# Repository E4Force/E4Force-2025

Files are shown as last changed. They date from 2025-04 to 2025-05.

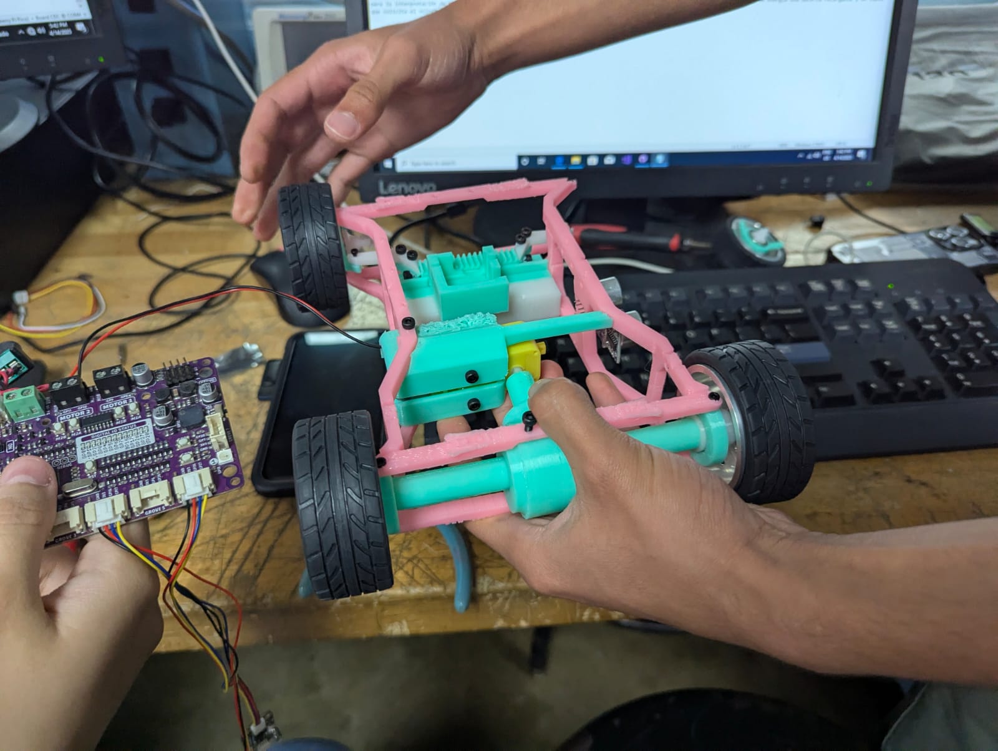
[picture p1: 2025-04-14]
other/prototype_original_mechanics.jpg

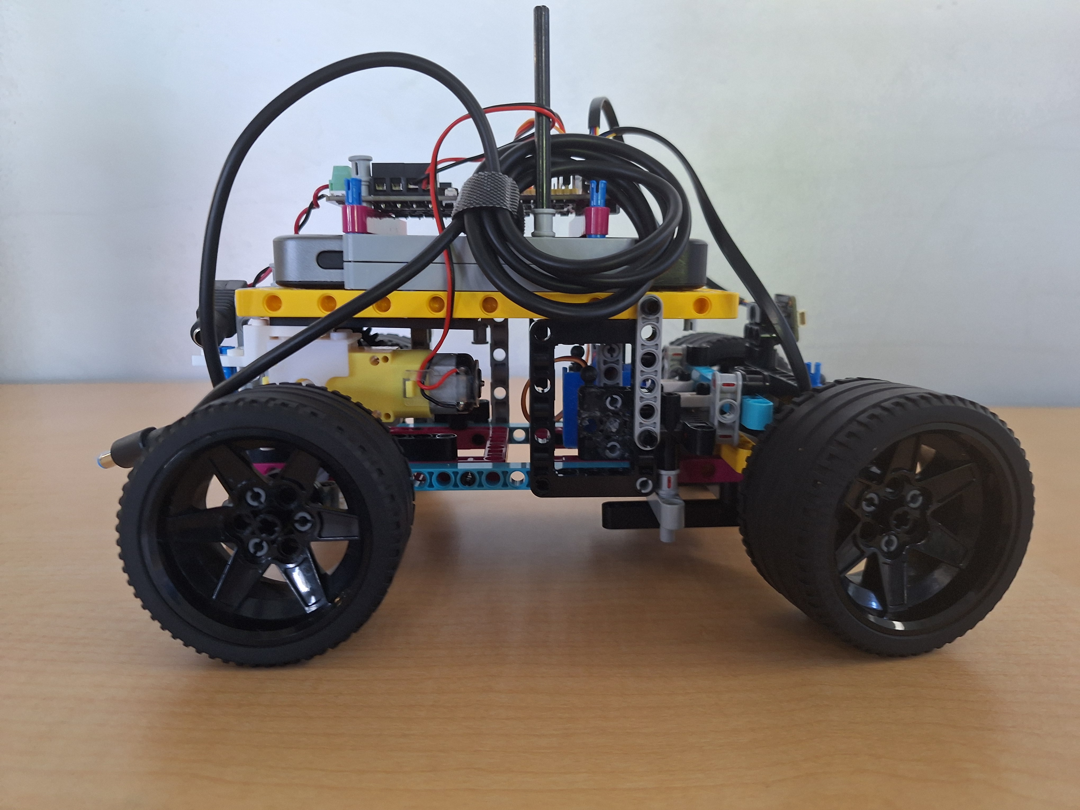
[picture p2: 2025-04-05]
v-photos/V1_car/20250405_082826.jpg

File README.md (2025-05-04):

# E4FORCE
This is a team that competes in the future engineers category with the mission of creating a autonomous car that is competitive and original. The members of this team are Efrain Ortiz Mulero and Elian Flores Medina, both students highlighted by there integration in the pre-engineering workshop (electronics) at Benjamin Harrison High School of Cayey, and Edianid González Morales, who recentely graduated from the same high school (and is presently studying at UPR university). Our autonomous car integrates color sensors and proximity sensors to detect obstacles in its way. It uses MicroPython as a software to interpret the data and Cythron Maker Pi RP2040 Pro as a hardware to execute instructions and manage the motors. We use a rechargeable battery as an energy source and a cable that requires the voltage to be 9V.

## Our Goals
- [] ~~four wheel drive~~
- [] ~~front wheel drive~~
- [x] rear wheel drive
- [x] [color library](/src/color.py)
- [x] [motors library](/src/motors.py)
- [x] [servo library](/src/servo.py)
- [x] [hc_sr04 library](/src/hc_sr04.py)
- [x] better documentation (better then last years documentation)
- [x] team pictures
- [x] [robot pictures](/v-photos/V1_car)
- [x] redisign robot
- [x] completly original mechanics

## Things we changed
- We changed the board (MOTION 2350 PRO) to an older one (Maker Pi 2040) since the one we were using had an error which affected a lot of the processes of programming because if we frequently uploaded a new code to the board, it would crash and everything would get corrupted. Sometimes we even needed to reinstall the MicroPhyton firmware. This was so often that in the WRO Open Championship in October 2024 we had to stop updating the code at least 10 minutes before each round because it was too risky.
- We started the design of our new car using Autodesk Fusion a 3d designing app for mechanical engineering.
- We decided to rewrite the color library do to the fact that it was very unorganized and looked kinda sloppy because the names of the definitions and the functions were written in a confusing way.

## Materials used to create the automous robot
- 3d pinter filament (sourced from ebay)
- 1x [Maker Pi 2040](https://www.adafruit.com/product/5129)
- 2x [APDS9960 Proximity, Light, RGB and Gesture sensor](https://www.adafruit.com/product/3595)
- 1x 35w JUOVI rechargeable battery (sourced from ebay)
- 1x [TT motor 1:48](https://www.adafruit.com/product/3777) 
- 1x MG90 servo (sourced from ebay)
- 4x bearing 6702 (sourced from ebay)
-  x M2 screws, M2.5 screws and M3 screws (sourced from aliexpress)
- 4x WLToys aluminum alloy wheels (sourced from aliexpress)
- 1x USB PD 9v trigger cable (sourced from ebay)

## Tools used to assemble our autonomous robot 
- 3D printer
- screwdriver
- sprue cutter

## 3d model sources
- [APDS9960 CAD by Adafruit](https://github.com/adafruit/Adafruit_CAD_Parts/tree/main/3595%20APDS9960%20Sensor)
- [TT motor CAD by Adafruit](https://github.com/adafruit/Adafruit_CAD_Parts/tree/main/3777%20TT%20Motor)
- [Maker Pi 2040 CAD by Cytron](https://www.cytron.io/p-maker-pi-rp2040-simplifying-robotics-with-raspberry-pi-rp2040)

## Our future plans
We plan to continue working on programing and 3d modeling until we become the best we can at both of them. Building an outstanding autonomus car in a visual way and functioning way is a big plan that we have in store for the future. In the future we will build are own color sensors that will be better then the one's we currently have and will read faster. We will make our future car 4x4 and add more sensors since it would be more efectivr but we thought about that a little to late hince we will use it for the future.

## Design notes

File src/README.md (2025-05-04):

## Purpose of each library

[color library](/src/color.py) We are using the color library to determine which way the robot car will turn ither left or right and even slow down the car depending on the color.

[hc_sr04 library](/src/hc_sr04.py) It will be used for detecting the walls of the track. If the car is too close to the wall, it will turn left or right depending on which side the wall is being detected from.

[motors library](/src/motors.py) The motor library is used for the autonomous car to move forward or backwards and if it has to stop, then it will stop moving.

[servo library](/src/servo.py) This library is used to turn the robot car left or right.

[timer library](/src/timer.py) It allows us to control time-related functions. We use it to time how long the servo should stay at a certain angle.

[main library](/src/main.py) This library combines all the libraries that we have, so all the functions have purpose for one another. For example, the color sensor will give a command to the motor and servo to do certain movements, and you can also combine the timer, so the motor is slowed down for a certain time and the servo will stay at a certain angle for a determined time.

## Crediting librarys
-[hc_sr04 library license](https://www.apache.org/licenses/LICENSE-2.0")

This directory must contain code for control software which is used by the vehicle to participate in the competition and which was developed by the participants.

All artifacts required to resolve dependencies and build the project must be included in this directory as well.

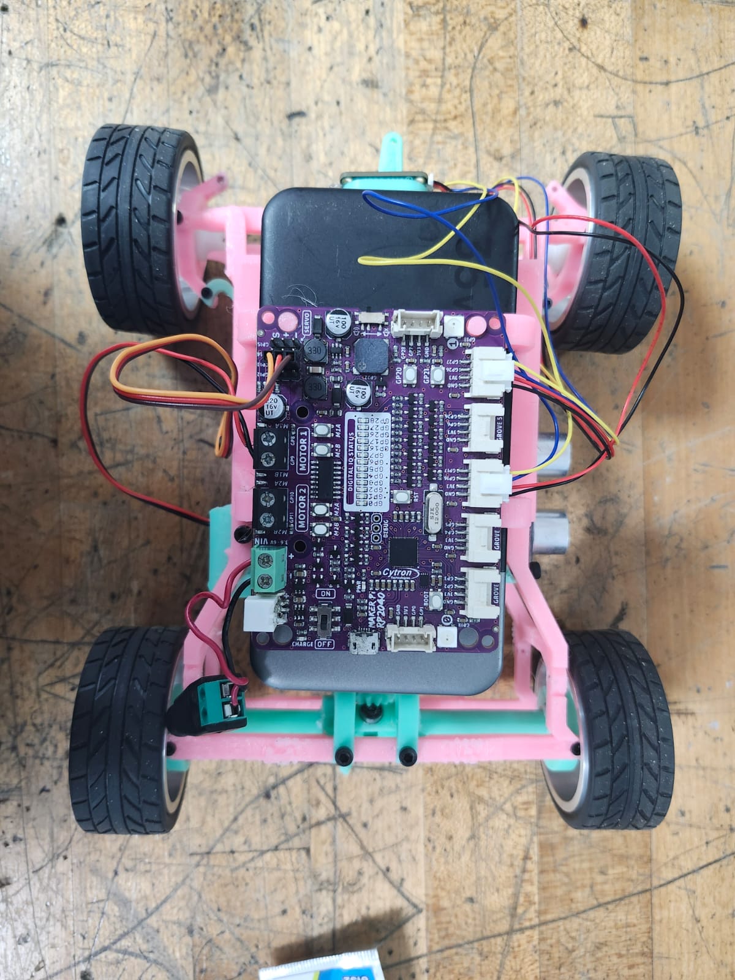
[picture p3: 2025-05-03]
v-photos/WhatsApp Image 2025-05-03 at 06.48.15_ce55268b.jpg

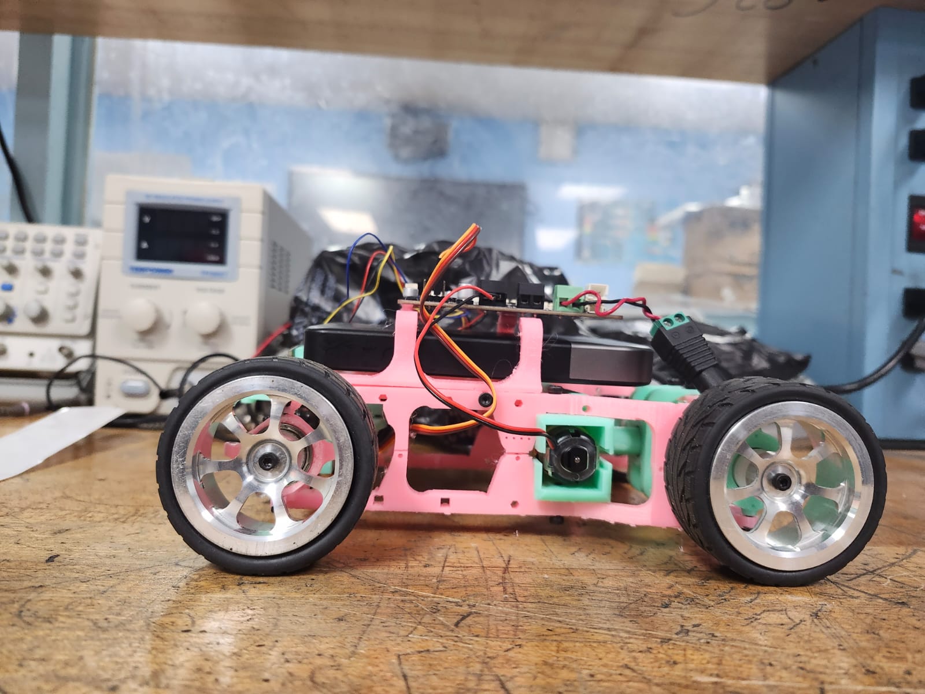
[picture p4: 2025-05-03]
v-photos/left.jpg

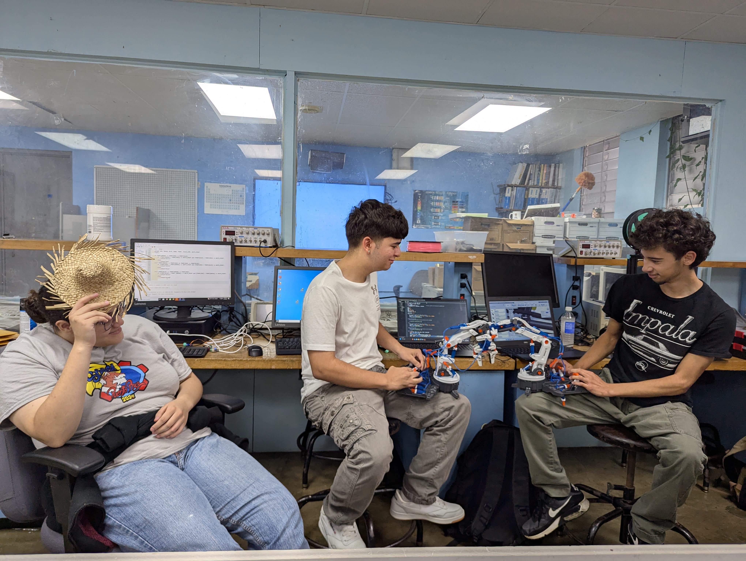
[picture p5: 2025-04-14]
t-photos/goofy_team_picture.jpg

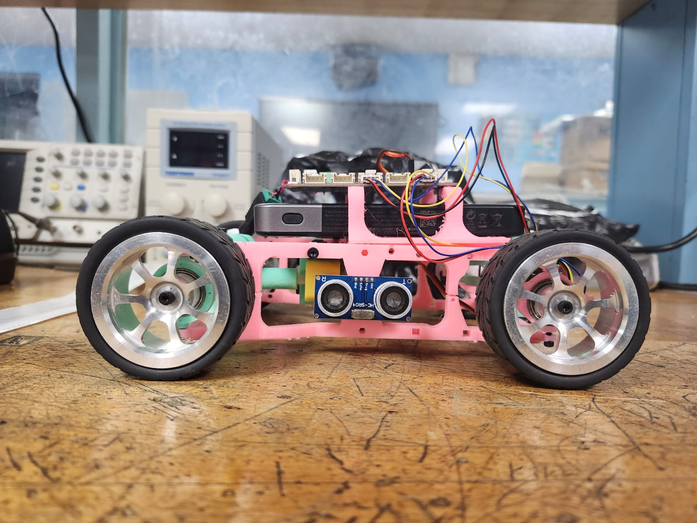
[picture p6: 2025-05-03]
v-photos/right.jpg

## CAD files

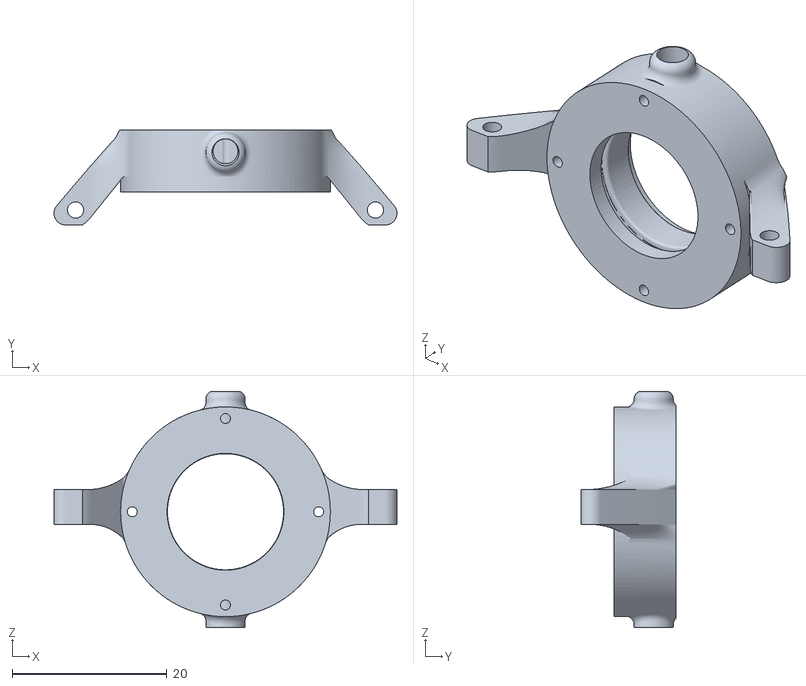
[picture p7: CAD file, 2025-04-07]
models/bearing front.stl
44.3 x 12.3 x 30.6

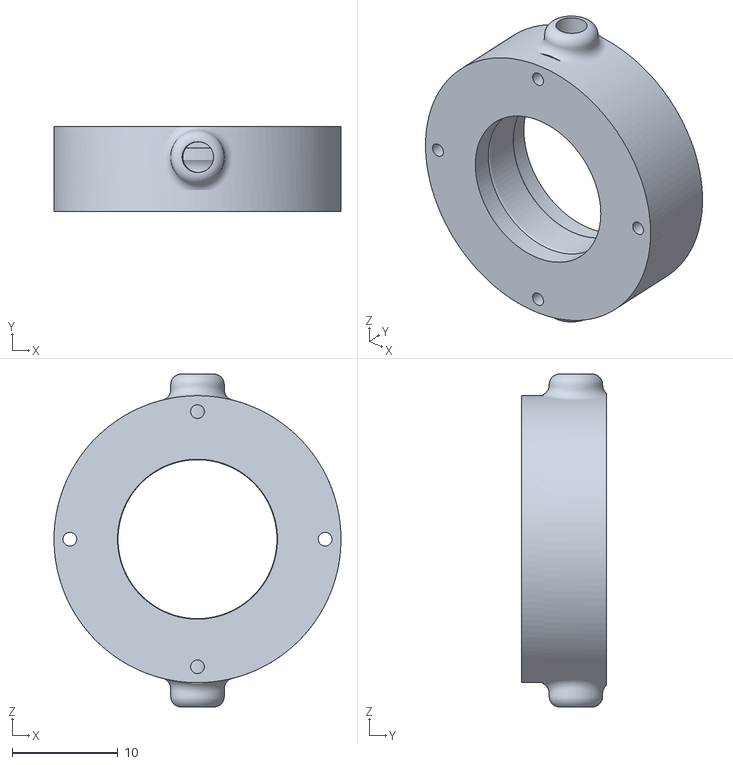
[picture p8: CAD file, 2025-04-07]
models/Car 3D parts/bearing back.stl
27.1 x 8.00 x 31.4

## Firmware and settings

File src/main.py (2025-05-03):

from machine import Pin, PWM, I2C
from time import sleep, sleep_ms
from servo import *
from motors import *
from hc_sr04 import *			# Library made by Roberto Sánchez, https://github.com/rsc1975/micropython-hcsr04.git
import utime
from apds9960.const import *					# https://github.com/liske/python-apds9960.git
from apds9960 import uAPDS9960 as APDS9960
from color import *
from timer import *


gp20 = Pin(20,Pin.IN)
gp21 = Pin(21,Pin.IN)

motor = m1()

motor.stop()

servo.center(13)



while True:
    
    if gp21.value() == False:
                
        white_calibration()
        sleep(.5)
        motor.forward(96)
        
        break
    
    
while True:
    
    COLOR_DOWN()
    if COLOR_DOWN() == "Red":
        motor.forward(93)
        servo.left(13)
        
        while True:
            COLOR_DOWN()
            if COLOR_DOWN() == "Blue":
                
                
                           
                
                sleep(.4)
            
                servo.center(13)
                motor.forward(96)
                sleep(.5)
           
                break
    elif COLOR_DOWN() == "Blue":
        motor.forward(93)
    
        servo.right(13)
        while True:
            COLOR_DOWN()
            if COLOR_DOWN() == "Red":
            
                
                sleep(.4)
                motor.forward(96)
                servo.center(13)
                sleep(.5)
                  
                break
while True:
    COLOR_FRONT()
    if COLOR_FRONT() == "Red":
        
        servo.left(13)
        sleep(1.5)
        servo.right(13)
        sleep(1)
        servo.center(13)
        sleep(.5)
        
        
    elif COLOR_FRONT() == "Blue":
        
        servo.right(13)
        sleep(1.5)
        servo.left(13)
        sleep(1)
        servo.center(13)
        sleep(.5)
        
    
    else:
        pass
        
        
        
        
    
    
    
    

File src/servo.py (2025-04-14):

from machine import Pin, PWM
import time

previous = "center"

class servo:
    
    def left(pin):
        global previous
        move = PWM(Pin(pin))
        move.freq(50)
        move.duty_ns(1_000_000)
        previous = "left"

    def right(pin):
        global previous
        move = PWM(Pin(pin))
        move.freq(50)
        move.duty_ns(2_000_000)
        previous = "right"

        
    def degrees(pin, deg):
        global previous
        calculated_duty = (1500000 + (10000*deg))        
        if calculated_duty >= 600000 and calculated_duty <= 2400000:
            move = PWM(Pin(pin))
            move.freq(50)
            move.duty_ns(int(calculated_duty))        
        elif calculated_duty < 600000:
            move = PWM(Pin(pin))
            move.freq(50)
            move.duty_ns(600000)                        
        elif calculated_duty > 2400000:
            move = PWM(Pin(pin))
            move.freq(50)
            move.duty_ns(2400000)            
        else:
            print("Not allowed")
            
        if deg < 0:
            previous = "left"
            
        elif deg > 0:
            previous = "right"
            
        elif deg == 0:
            previous = "center"
           
    def center(pin):
        compensation = 20
        global previous
        move = PWM(Pin(pin))
        move.freq(50)
        if previous == "center":		# No compensation is needed, hence the degrees are 0
            servo.degrees(pin, 0)           
        elif previous == "left":					# Some compensation is needed to make the car go straight
            servo.degrees(pin, compensation)		# hence the compensation where the 0 degrees would go        
        elif previous == "right":					# since there is some play in the rack and pinion
            servo.degrees(pin, -compensation)
        
                    
    def stop(pin):
        move = PWM(Pin(pin))
        move.deinit()
        
    def test(pin):
        servo.center(pin)
        time.sleep(1)
        servo.left(pin)
        time.sleep(1)
        servo.center(pin)
        time.sleep(1)
        servo.right(pin)
        time.sleep(1)
        servo.center(pin)
        

        

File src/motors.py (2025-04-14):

from machine import Pin, PWM

class m1:
    
    def __init__(self, freq=120):
        self.m1a = PWM(Pin(8))
        self.m1b = PWM(Pin(9))
        self.m1a.freq(freq)
        self.m1b.freq(freq)
        
    def forward(self, speed):
        self.m1a.duty_u16(int(2**(speed/6.25)))
        self.m1b.duty_u16(0)
        
    def reverse(self, speed):
        self.m1a.duty_u16(0)
        self.m1b.duty_u16(int(2**(speed/6.25)))
        
    def stop(self):
        self.m1a.duty_u16(0)
        self.m1b.duty_u16(0)
        
class m2:
    
    def __init__(self, freq=120):
        self.m2a = PWM(Pin(10))
        self.m2b = PWM(Pin(11))
        self.m2a.freq(freq)
        self.m2b.freq(freq)
        
    def forward(self, speed):
        self.m2a.duty_u16(int(2**(speed/6.25)))
        self.m2b.duty_u16(0)
        
    def reverse(self, speed):
        self.m2a.duty_u16(0)
        self.m2b.duty_u16(int(2**(speed/6.25)))
        
    def stop(self):
        self.m2a.duty_u16(0)
        self.m2b.duty_u16(0)
        
class m3:
    
    def __init__(self, freq=120):
        self.m3a = PWM(Pin(12))
        self.m3b = PWM(Pin(13))
        self.m3a.freq(freq)
        self.m3b.freq(freq)
        
    def forward(self, speed):
        self.m3a.duty_u16(int(2**(speed/6.25)))
        self.m3b.duty_u16(0)
        
    def reverse(self, speed):
        self.m3a.duty_u16(0)
        self.m3b.duty_u16(int(2**(speed/6.25)))
        
    def stop(self):
        self.m3a.duty_u16(0)
        self.m3b.duty_u16(0)
        
class m4:
    
    def __init__(self, freq=120):
        self.m4a = PWM(Pin(14))
        self.m4b = PWM(Pin(15))
        self.m4a.freq(freq)
        self.m4b.freq(freq)
        
    def forward(self, speed):
        self.m4a.duty_u16(int(2**(speed/6.25)))
        self.m4b.duty_u16(0)
        
    def reverse(self, speed):
        self.m4a.duty_u16(0)
        self.m4b.duty_u16(int(2**(speed/6.25)))
        
    def stop(self):
        self.m4a.duty_u16(0)
        self.m4b.duty_u16(0)

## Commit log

2025-04-07 Add files via upload
    This was our second milestone, we finished the concept of universal joints, differential, and started the steering system which is probably the hardest thing we faced back in November 2024. as the old car had problems with it being "too loose".
2025-04-07 Added some models
    Models from differential and bearings added, and some models which we consider milestones from our weekly work
    [bearing back.stl, bearing front.stl]
2025-04-07 V1 car model
    The first version of our car (before 3d printing)
2025-04-08 Classified types of 3D models
    [bearing back.stl, bearing front.stl]
2025-04-13 Progress of April 12 and 13
    This is the functional model, the only thing left where the board and battery will be placed at (ignore the front axle and differential those are for what we are planning on the future).
2025-04-14 Color library update
    [bearing back.stl, bearing front.stl]
2025-04-14 Pictures
    adding the photos of our team and testing prototype of our autonomous robot.
2025-05-03 Last changes
    Final car fotos and upload of main and timer
